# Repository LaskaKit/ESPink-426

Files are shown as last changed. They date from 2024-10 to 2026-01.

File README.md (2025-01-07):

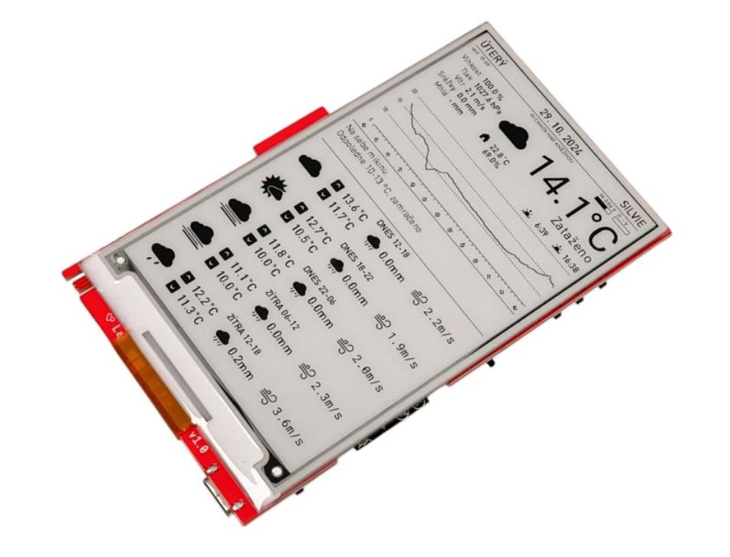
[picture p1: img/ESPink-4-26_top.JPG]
ESPink-4.26 TOP

</br>
# ESPink 4.26" - versatile and low power board with ESP32-S3 for big 4.26" 800x480 ePaper/eInk
Our completely finished and equipped development boards with ESP32 and glued ePaper display became popular not only among DIY makers. We are now expanding our product range with another finished Laskakit ESPink development kit with a 4.26" variant. </br>
It complements the existing family of ready to use ePaper kits such as Laskakit [ESPink-Shelf-2.9 ESP32 e-Paper](https://www.laskakit.cz/laskakit-espink-shelf-2-9-esp32-e-paper/?variantId=14193), [LaskaKit ESPink-4.2 ESP32 e-Paper](https://www.laskakit.cz/laskakit-espink-42-esp32-e-paper-pcb-antenna/?variantId=13538) and LaskaKit [ESPink-Shelf-2.13 ESP32 e-Paper](https://www.laskakit.cz/laskakit-espink-shelf-213-esp32-e-paper/).
If you prefer a standalone board, then we offer the [very low power and versatile ESPink](https://www.laskakit.cz/laskakit-espink-esp32-e-paper-pcb-antenna/?variantId=12419). The board is smaller and more versatile for connecting other ePaper displays.</br>
</br>
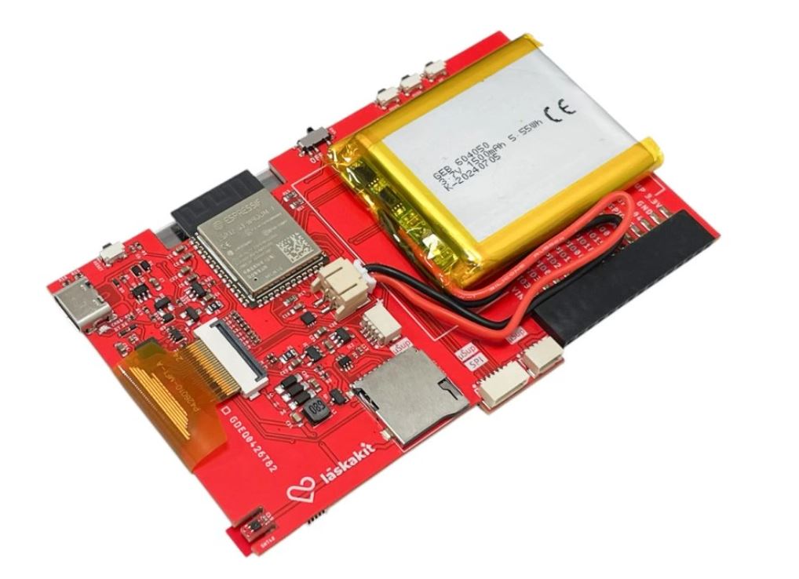
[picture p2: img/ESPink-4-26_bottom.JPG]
ESPink-4.26 TOP
</br>
ESPink-4.26 with ESP32-S3 offers very low power consumption, reasonably sized ePaper with large 800x480px resolution, easy programming thanks to built-in programmer connected to USB-C from which the battery is also charged, connector with unused pins from ESP32-S3 thanks to which additional signals can be brought to the board and last but not least a microSD slot for memory card. </br>
ESPink-4.26 is equipped with two of our universal I2C uŠup connectors to which you can connect various sensors - [SHT40 (temperature, humidity)](https://www.laskakit.cz/laskakit-sht40-senzor-teploty-a-vlhkosti-vzduchu/), [BME280 (tlak, teplota, vlhkost)](https://www.laskakit.cz/arduino-senzor-tlaku--teploty-a-vlhkosti-bme280/), [SCD41 (CO2, temperature, humidity)](https://www.laskakit.cz/laskakit-scd41-senzor-co2--teploty-a-vlhkosti-vzduchu/), [BH1750 (light sensor)](https://www.laskakit.cz/laskakit-bh1750-snimac-intenzity-osvetleni/), [APDS-9960 (gesture sensor)](https://www.laskakit.cz/laskakit-apds-9960-senzor-priblizeni-a-gest/) and lot of other sensors.</br>
Our I2C uŠup connector is compatible with Adafruit Stemma and Qwiik from Sparkfun.</br>
In addition to the I2C uŠup connector, we also have an SPI uŠup connector.</br>
</br>
The board supports the popular Živý Obraz project which greatly simplifies the use of the ePaper display to display photos, (google, outlook, apple) calendar, weather station readings, weather forecasts and much more. No need to write code, just upload the correct type of ePaper and board through the web environment and follow the procedure described in [wiki of project](https://wiki.zivyobraz.eu/).</br>
The firmware you may upload to board through [webpage available on this link](https://zivyobraz.eu/?page=instalace), just choose the board <b>LaskaKit ESPink 3.x</b> aand the type of ePaper <b>GDEQ0426T82</b>. </br>
</br>
If you want to write your own program, go ahead :-)</br>
The [schematic of board you may find on](https://github.com/LaskaKit/ESPink-426/tree/main/HW) and we also wrote several [example codes](https://github.com/LaskaKit/ESPink-426/tree/main/SW), which help a lot with writing of you own firmware for this ESPink-4.26 board.</br>
</br>
Some technical information:</br>
ESPink-4.26 has a switch that completely disconnects the board and ePaper from the power supply. Both battery and USB. </br>
IO pins for I2C bus are used - SDA IO42 and SCL IO2.</br>
The board can be assembled with a SHT40, which is connected to the same I2C bus as the external sensors.</br>
The power supply for the external I2C sensors (uSup), SPI sensors (uSup), mounted SHT40 sensor, Fuel Gauge MAX17048 and ePaper is switched via GPIO pin 47. Active in HIGH.</br>
Battery status is monitored by the Fuel Gauge MAX17048 sensor connected to the same I2C bus.</br>
In addition to the RESET button, there are three other buttons on the board labeled UP (GPIO39), PUSH (GPIO40) and DOWN (GPIO41) - all active in LOW.</br>
IO pins for the SPI bus are used - CS IO46, MOSI IO37, CLK IO14 and MISO IO21.</br>
## The ESPink-4.26 is available on [https://www.laskakit.cz/laskakit-espink-4-26-esp32-s3-e-paper/](https://www.laskakit.cz/laskakit-espink-4-26-esp32-s3-e-paper/)

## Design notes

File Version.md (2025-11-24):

### Version 1.4
- Added one more capacitor 47uF for ESP
#### Version 1.3
- Fuel Gauge replaced by ESP ADC
- Epaper BUSY pin changed from IO36 to IO38
- Epaper CS2 pin changed from IO35 to IO18
- µŠup SPI MOSI pin changed from IO37 to IO3
#### Version 1.2
- LOD changed to RT9080
- Changed pull-ups R18, R19, R20 back from VSENSOR to +3.3V
- Buttons moved far away one from each other
- Rotated uSup connector -90 deg.
#### Version 1.1
- Changed pull-ups R13, R14, R18, R19, R20 and R22 from +3.3V to VSENSOR
- Debounsing for buttons
- Battery connector moved
#### Version 1.0
- Initial | Počáteční

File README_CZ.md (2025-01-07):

ESPink-4.26 TOP
</br>
# ESPink-4.26" - univerzální a velmi úsporná deska s ESP32-S3 pro velký 4.26" 800x480 ePaper

Do obliby nejen bastlířů se dostaly naše už kompletně hotové a osazené vývojové desky s ESP32 a přilepeným ePaper displejem. Rozšiřujeme tak náš sortiment o další hotový vývojový kit Laskakit ESPink o variantu 4.26". </br>
Doplňuje tak stávající rodinu hotových kitů s ePaper jako jsou [Laskakit ESPink-Shelf-2.9 ESP32 e-Paper](https://www.laskakit.cz/laskakit-espink-shelf-2-9-esp32-e-paper/?variantId=14193), [LaskaKit ESPink-4.2 ESP32 e-Paper](https://www.laskakit.cz/laskakit-espink-42-esp32-e-paper-pcb-antenna/?variantId=13538) a [LaskaKit ESPink-Shelf-2.13 ESP32 e-Paper](https://www.laskakit.cz/laskakit-espink-shelf-213-esp32-e-paper/).</br>
Pokud preferuješ samostatnou desku, pak máme v nabídce [velmi úsporný a univerzální ESPink](https://www.laskakit.cz/laskakit-espink-esp32-e-paper-pcb-antenna/?variantId=12419). Deska je menší a univerzálnější pro připojení jiných ePaper displejů. </br>
</br>
ESPink-4.26 TOP</br>
</br>
ESPink-4.26 s ESP32-S3 nabízí velmi nízkou spotřebu, rozumně velký ePaper s velkým 800x480px rozlišením, jednoduché programování díky vestavěnému programátoru připojeného na USB-C ze kterého se zároveň nabíjí akumulátor, konektor s vyvedenými nevyužitými piny z ESP32-S3 díky kterému mohou být do desky přivedeny další signály a v neposlední řadě i microSD slot pro paměťovou kartu. </br>
</br>
ESPink-4.26 má osazeny dva naše univerzální I2C uŠup konektory ke kterým můžeš připojit nejrůznější čidla - [SHT40 (teplota, vlhkost)](https://www.laskakit.cz/laskakit-sht40-senzor-teploty-a-vlhkosti-vzduchu/), [BME280 (tlak, teplota, vlhkost)](https://www.laskakit.cz/arduino-senzor-tlaku--teploty-a-vlhkosti-bme280/), [SCD41 (CO2, teplota, vlhkost)](https://www.laskakit.cz/laskakit-scd41-senzor-co2--teploty-a-vlhkosti-vzduchu/), [BH1750 (osvětlení)](https://www.laskakit.cz/laskakit-bh1750-snimac-intenzity-osvetleni/), [APDS-9960 (senzor gest)](https://www.laskakit.cz/laskakit-apds-9960-senzor-priblizeni-a-gest/) a spoustu další senzorů. Náš I2C uŠup konektor je kompatibilní s Adafruit Stemma a Qwiik od Sparkfun.</br>
Kromě I2C uŠup konektoru máme osazený i SPI uŠup konektor.
</br>
Deska podporuje populární projekt Živý Obraz, který výrazně zjednodušuje použití ePaper displeje k zobrazení fotografií, (google, outlook, apple) kalendáře, kurzů, hodnot z meteostanic, předpovědi počasí a mnoho dalšího. Není nutné psát kód, stačí nahrát správný typ ePaper a desky skrze webové prostředí a dodržet postup popsaný v [dokumentaci](https://wiki.zivyobraz.eu/).</br>
Program nahraješ [přes webové prostředí na této stránce](https://zivyobraz.eu/?page=instalace) a stačí zvolit desku <b>LaskaKit ESPink 3.x</b> a typ ePaperu <b>GDEQ0426T82</b>. </br>
</br>
Pokud si chceš napsat vlastní program, tak do toho :-)</br>
Na našem github máš [schéma desky](https://github.com/LaskaKit/ESPink-426/tree/main/HW) a nezapomněli jsme ani na [vzorové kódy](https://github.com/LaskaKit/ESPink-426/tree/main/SW), které by ti značně měly usnadnit programování a práci s naším ESPink-4.26. </br>
</br>
Pár technických informací:</br>
ESPink-4.26 má přepínač kterým se deska i ePaper kompletně odpojí od napájení. Jak baterie, tak i USB. </br>
IO piny pro I2C sběrnici jsou použity - SDA IO42 a SCL IO2.</br>
Na desce může být osazen SHT40, který je připojen na stejnou I2C sběrnici jako externí čidla.</br>
Napájení pro externí I2C čidla (uŠup), SPI čidla (uŠup), osazené SHT40 čidlo, Fuel Gauge MAX17048 a ePaper je spínán přes GPIO pin 47. Aktivní v HIGH.</br>
Stav baterie je monitorován Fuel Gauge senzorem MAX17048 připojeným na stejnou I2C sběrnici.</br>
Kromě RESET tlačítka jsou na desce osazena další tři tlačítka označená jako UP (GPIO39), PUSH (GPIO40) a DOWN (GPIO41) - všechny aktivní v LOW.</br>
IO piny pro SPI sběrnici jsou použity - CS IO46, MOSI IO37, CLK IO14 a MISO IO21.</br> 

## ESPink-4.26 je k zakoupení na našem e-shopu [https://www.laskakit.cz/laskakit-espink-4-26-esp32-s3-e-paper/](https://www.laskakit.cz/laskakit-espink-4-26-esp32-s3-e-paper/)

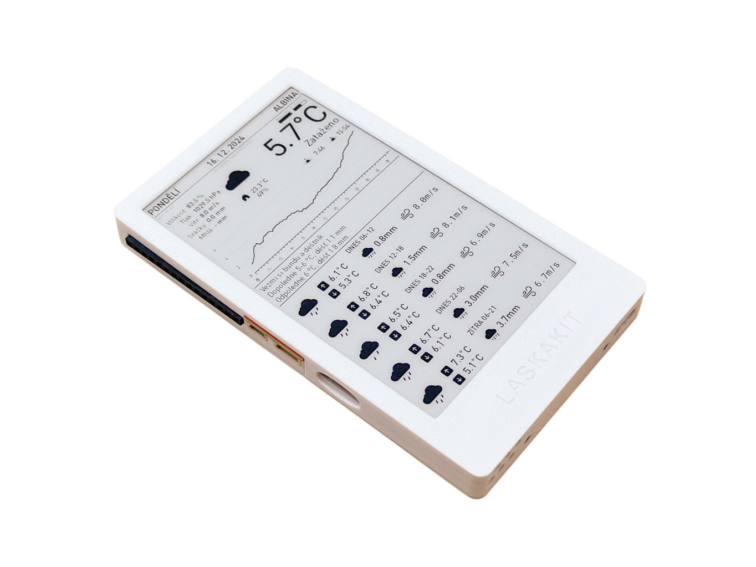
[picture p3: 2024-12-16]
img/laskakit--krabicka-pro-espink-4-26-2.jpg

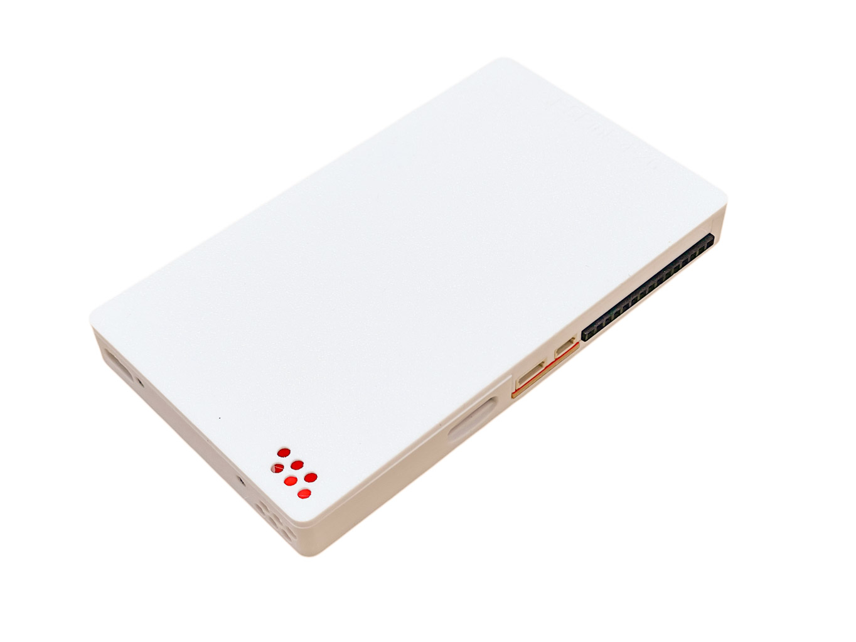
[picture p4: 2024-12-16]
img/laskakit--krabicka-pro-espink-4-26-3.jpg

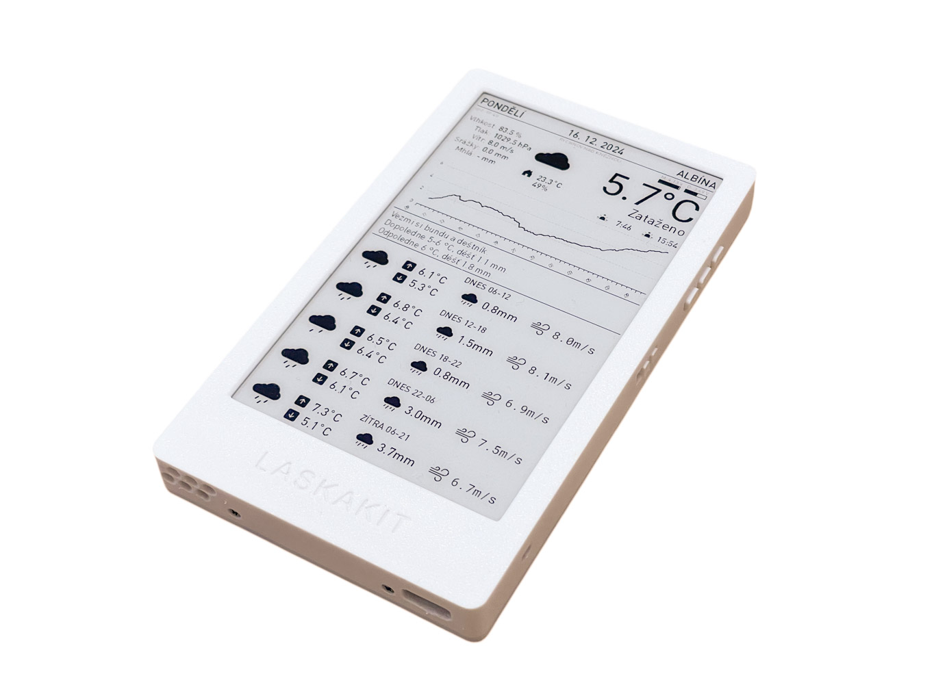
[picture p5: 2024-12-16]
img/laskakit--krabicka-pro-espink-4-26-1.jpg

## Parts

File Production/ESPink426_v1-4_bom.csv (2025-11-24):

Comment | Designator | Footprint | LCSC Part #
1.3M | R25 | R0402
1M | R8 R24 | R0402
1TS003B-1600-3500A | DOWN PUSH RESET UP | 1TS003B16003500A
1k | R5 | R0402
1uF | C7 | C0603
1uF | C29 C30 C31 | C0402
1uF/25V | C9 C10 C11 C16 | C0402
1x15 | JP1 | 1X15-F-SMD
2.2R | R9 | R0402
3.3k | R10 | R0402
4.7k | R13 R14 | R0603
4.7uF/25V | C3 C8 C12 C13 C14 C15 | C0402
4.7uF/25V | C20 | C0603
5.1k | R15 R16 | R0402
5.8A/30V/35mΩ | Q4 | SOT23-3 | C20917
10k | R1 R2 R3 R6 R11 R18 R19 R20 R22 | R0402
10uF/16V | C4 C5 C24 C25 | C0603
10uF/25V | C21 | C0603
22uF | C26 | C0603
47k | R4 R7 | R0402
47uF | C2 C22 | C0603 | C178330
47uH/1A | L1 | SMNR4020
100k | R12 R23 | R0402
100n | C27 C28 | C0402
100nF | C1 | C0603
100nF | C6 C17 C18 C19 | C0402
AO3401 | Q5 Q7 | SOT23
BAT60B | D3 | SOD323-R
CH9102F | IC3 | QFN24-4X4
DMG2305UX | Q2 | MICRO3 | C144153
ESP32-S3-WROOM-1-N16R8 | IC1 | ESP32S3WROOM1N16
GDEQ0426T82 | U$4 | GDEQ0426T82
JST-PH-2_SMD/90SMD | BATTERY | S2B-PH-SM4 | C47647
JST-SH-4_RA | J2 | 1X04_1MM_RA
JST-SH-4_VERT | J3 | 1X04_1MM_RA
LESD5D5.0CT1G | D7 D8 D9 | LESD5D50CT1G
MBR0530 | D4 D5 D6 | SOD123-F
MICRO_SD | SD_CARD | MICRO_SD | C91145
MMDT3904 | Q1 | SC70-6 | C268586
MMDT5401 | Q3 | SC70-6 | C54540
RED | CHRG | CHIP-LED0603 | C2286
RT9080-33GJ5 | IC2 LDO | SOT94P280X100-5N
SHT40 | SHT40 | SHT40
SMF05C | IC4 | SOT65P210X110-6N | C558425
SSSS811101 | SW1 | SSSS811101
TP4054 | U1 | SOT-23-5 | C32574
USB-C_GT-USB-7010B | J4 | G-SWITCH_GT-USB-7010B | C2837092
USUP_SPI_CONNECTOR | J5 | 1X06_1MM_RA

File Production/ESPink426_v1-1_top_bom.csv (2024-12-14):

Comment | Designator | Footprint | LCSC Part #
1M | R8 | R0402
1TS003B-1600-3500A | DOWN PUSH RESET UP | 1TS003B16003500A
1k | R5 | R0402
1uF | C7 | C0603
1uF | C29 C30 C31 | C0402
1uF/25V | C9 C10 C11 C16 | C0402
2.2R | R9 | R0402
4.7k | R13 R14 | R0603
4.7uF | C5 | C0603 | C99229
4.7uF/25V | C3 C8 C12 C13 C14 C15 | C0402
4.7uF/25V | C20 | C0603
5.1k | R15 R16 | R0402
10k | R1 R2 R3 R11 R18 R19 R20 R22 | R0402
10uF/25V | C21 | C0603
22uF | C4 C22 C23 C24 C25 C26 | C0603
47uF | C2 | C0603 | C178330
47uH/1A | L1 | SMNR4020 | C467067
100k | R12 R23 | R0402
100n | C27 C28 | C0402
100nF | C1 | C0603
100nF | C6 C17 | C0402
100nF | C18 | C0603
100nF | C19 | C0402
330 | R10 | R0402
AO3400A | Q4 | SOT23-3 | C20917
AO3401 | Q5 Q7 | SOT23
AP2191WG-7 | IC7 | SOT25 | C141321
BAT60B | D1 D2 D3 | SOD323-R
CH9102F | IC3 | QFN24-4X4
ESP32-S3-WROOM-1-N16 | IC1 | ESP32S3WROOM1N16
GDEQ0426T82 | U$4 | GDEQ0426T82
HT7833 | LDO | SOT23-5 | C164106
JST-PH-2/90SMD | BATTERY | S2B-PH-SM4 | C47647
JST-SH-4_RA | J2 | 1X04_1MM_RA | C145956
JST-SH-4_VERT | J3 | 1X04_1MM_RA | C145956
LESD5D5.0CT1G | D7 D8 D9 | LESD5D50CT1G
MAX17048 | U2 | TDFN-8 | C2682616
MBR0530 | D4 D5 D6 | SOD123-F
ME6211C33M5G | IC2 | SOT23-5
MICRO_SD | SD_CARD | MICRO_SD | C91145
MMDT3904 | Q1 | SC70-6 | C268586
POLIFUSE0500805L | F1 F2 | 0805L
RED | CHRG | CHIP-LED0603 | C2286
SHT40 | SHT40 | SHT40
SMF05C | IC4 | SOT65P210X110-6N | C558425
SSSS811101 | SW1 | SSSS811101
TP4054 | U1 | SOT-23-5 | C32574
USB-C_2-16PIN | J4 | USBC_USB-C-16P-5 | C2837092
USUP_SPI_CONNECTOR | J5 | 1X06_1MM_RA
1x15P | JP1 | 1x15P | C5142248

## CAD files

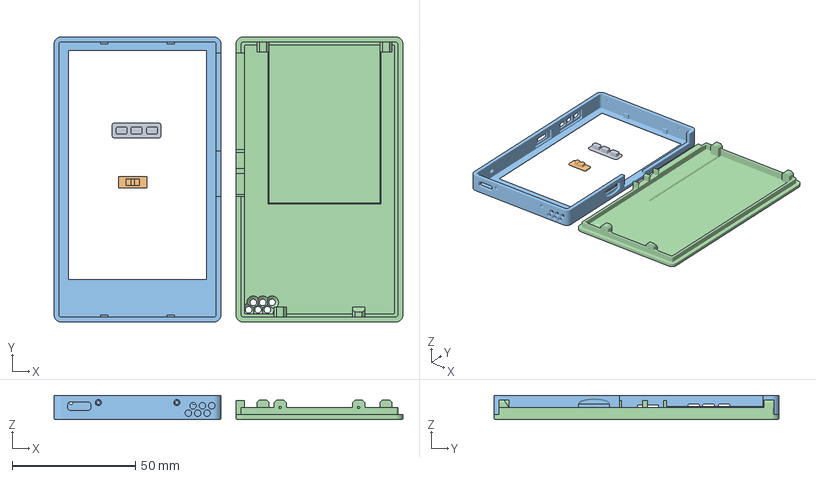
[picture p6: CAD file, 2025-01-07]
3D/ESPink-426_case_v1-1.3mf
141.8 x 115.9 x 9.80 mm
buttons v22
switch v8
Top_cover v73
Bottom_cover v28

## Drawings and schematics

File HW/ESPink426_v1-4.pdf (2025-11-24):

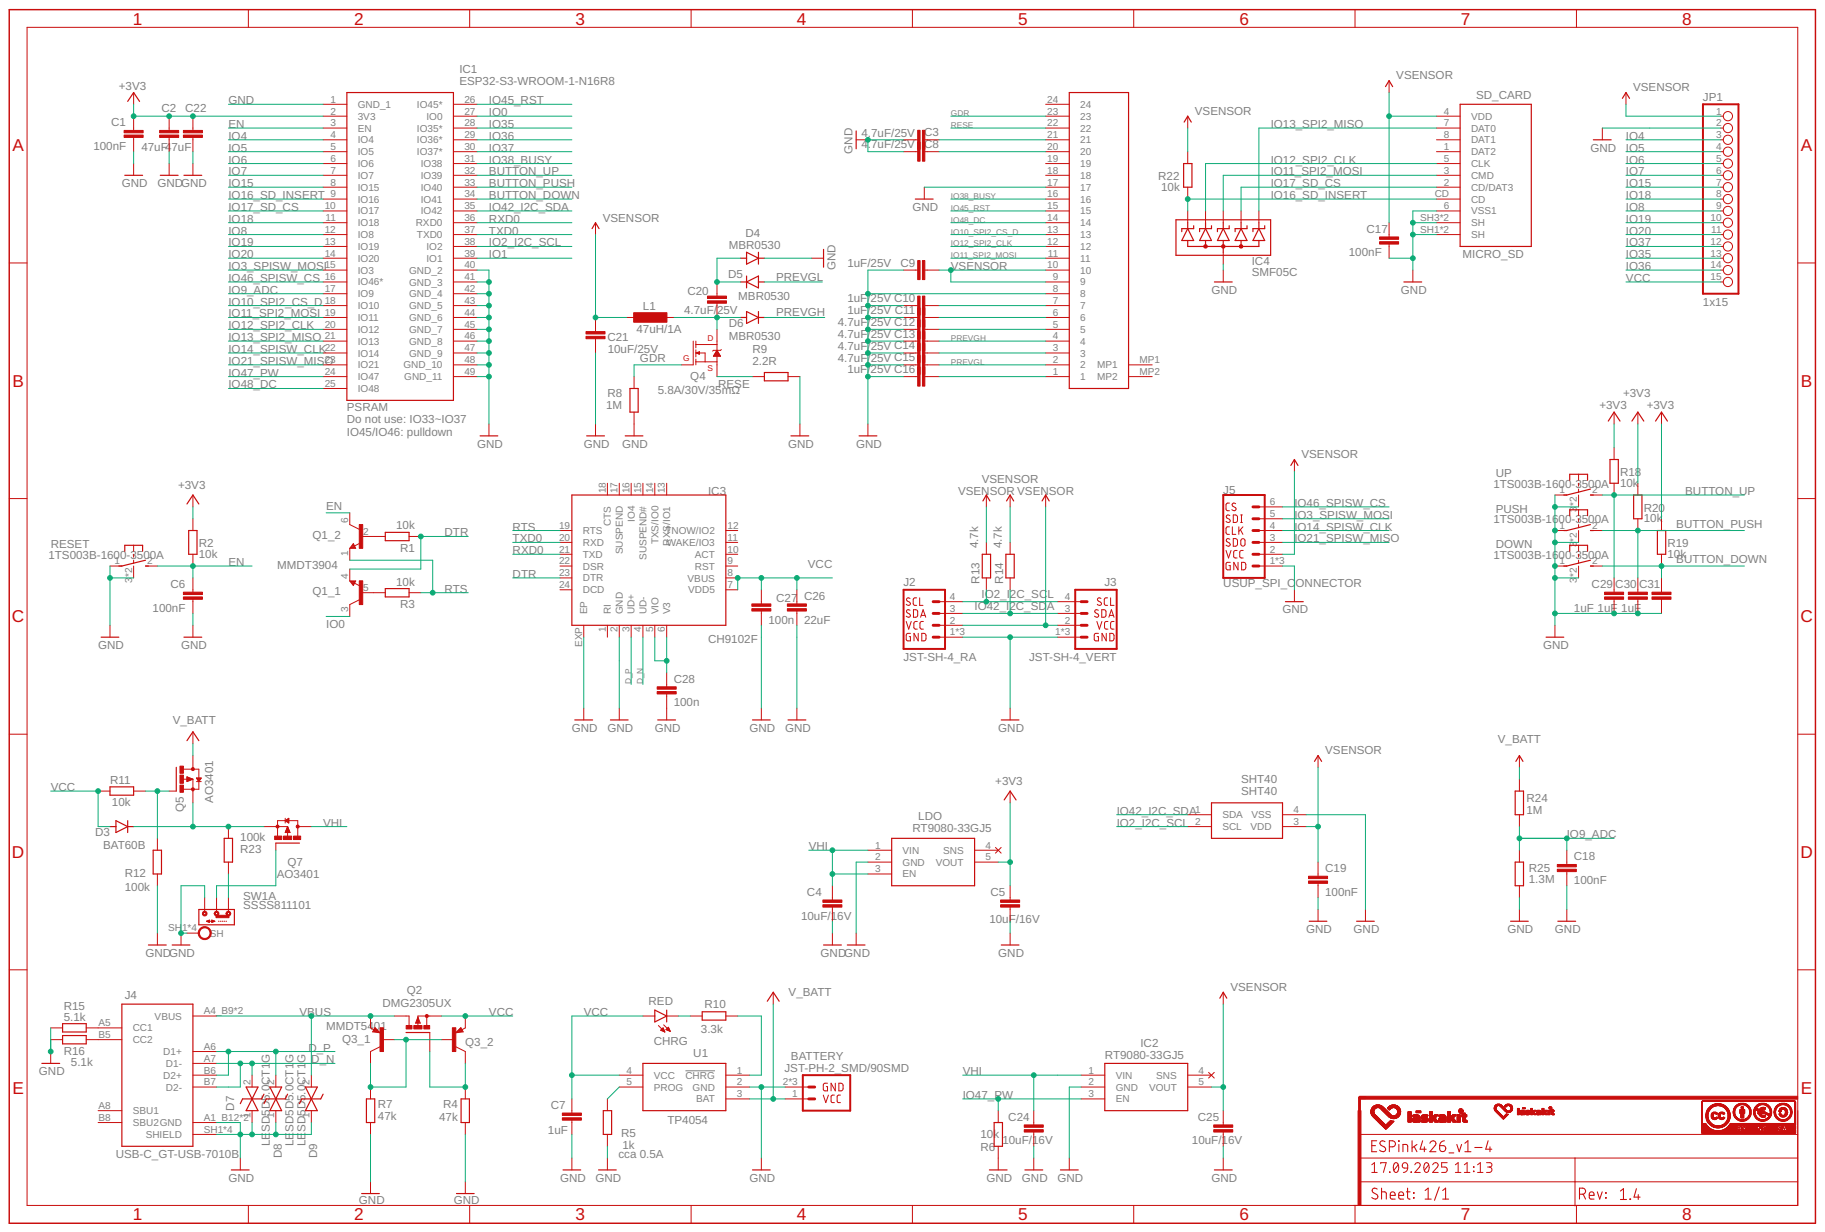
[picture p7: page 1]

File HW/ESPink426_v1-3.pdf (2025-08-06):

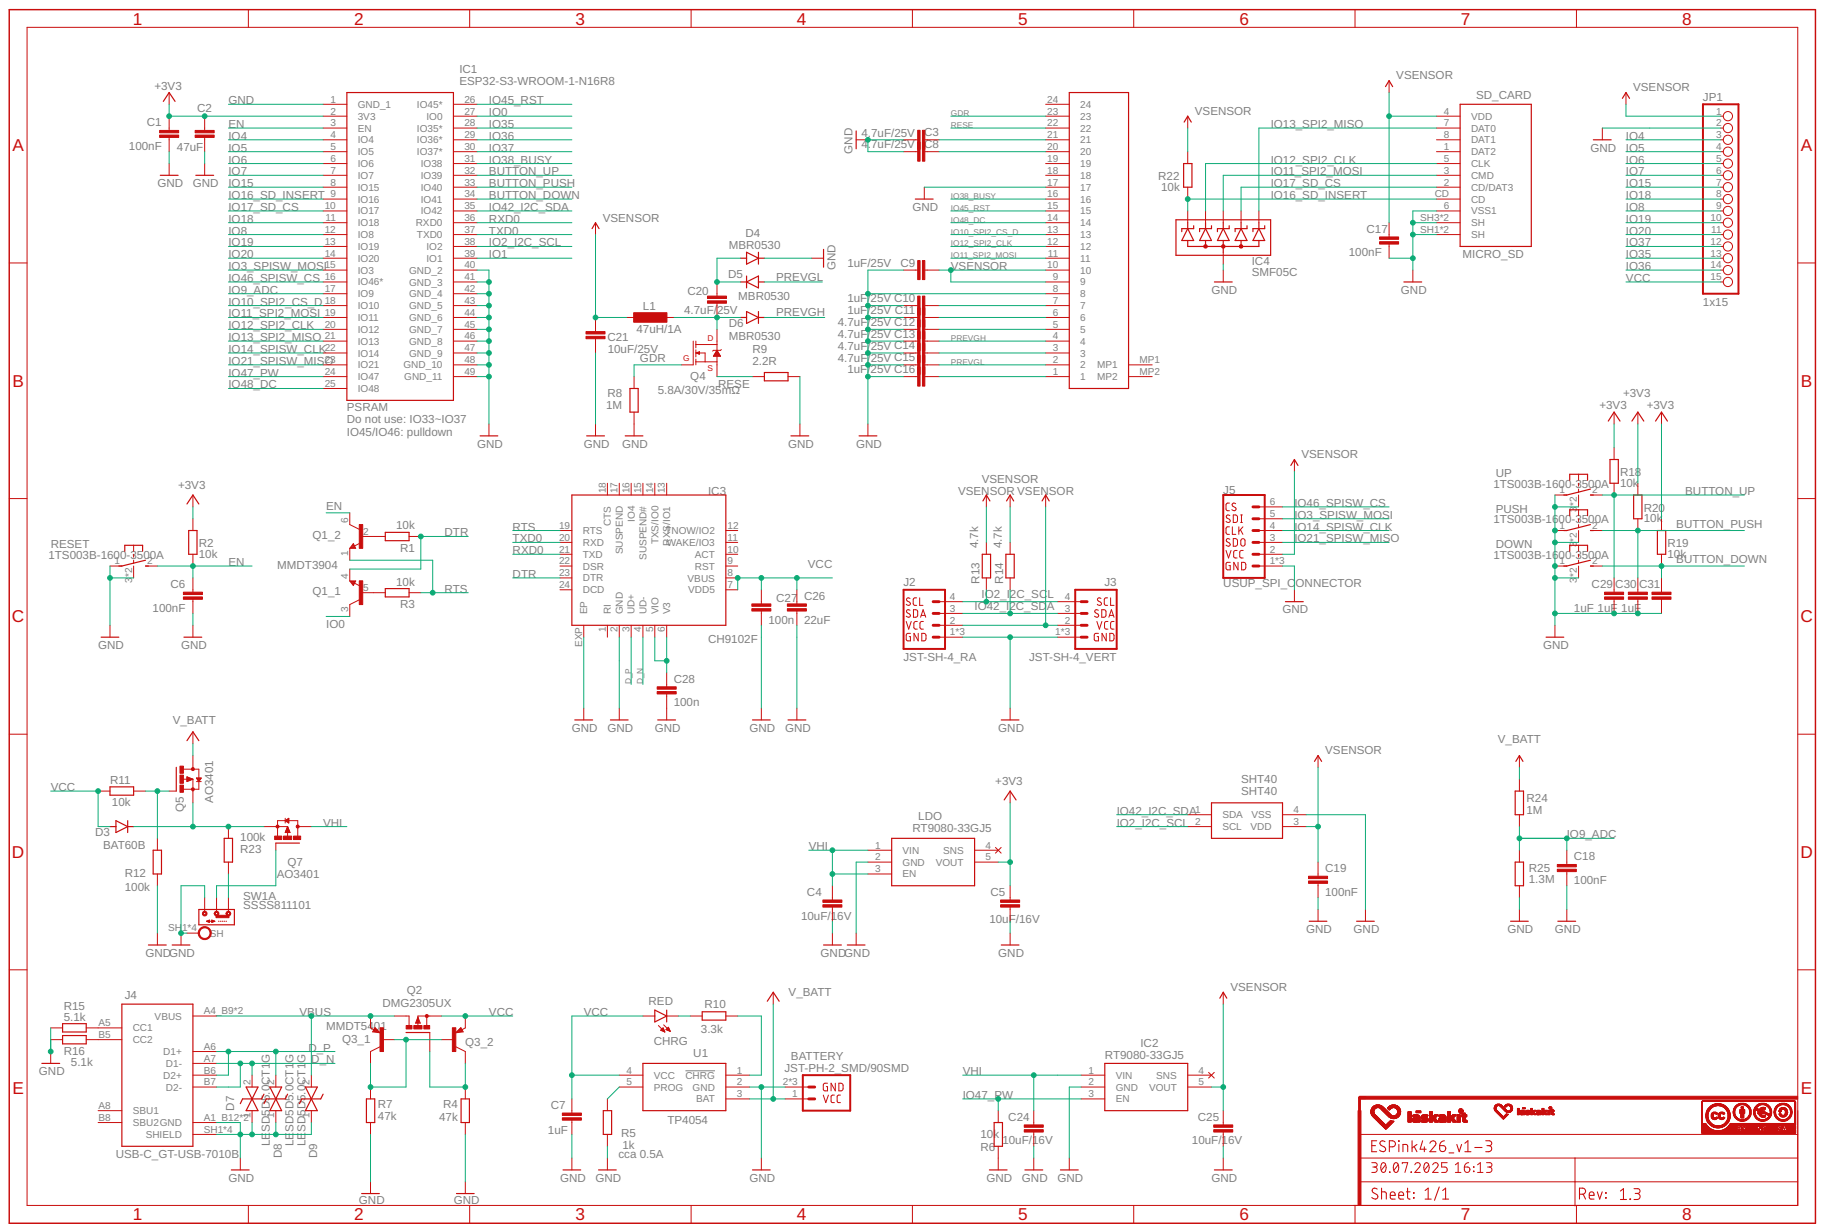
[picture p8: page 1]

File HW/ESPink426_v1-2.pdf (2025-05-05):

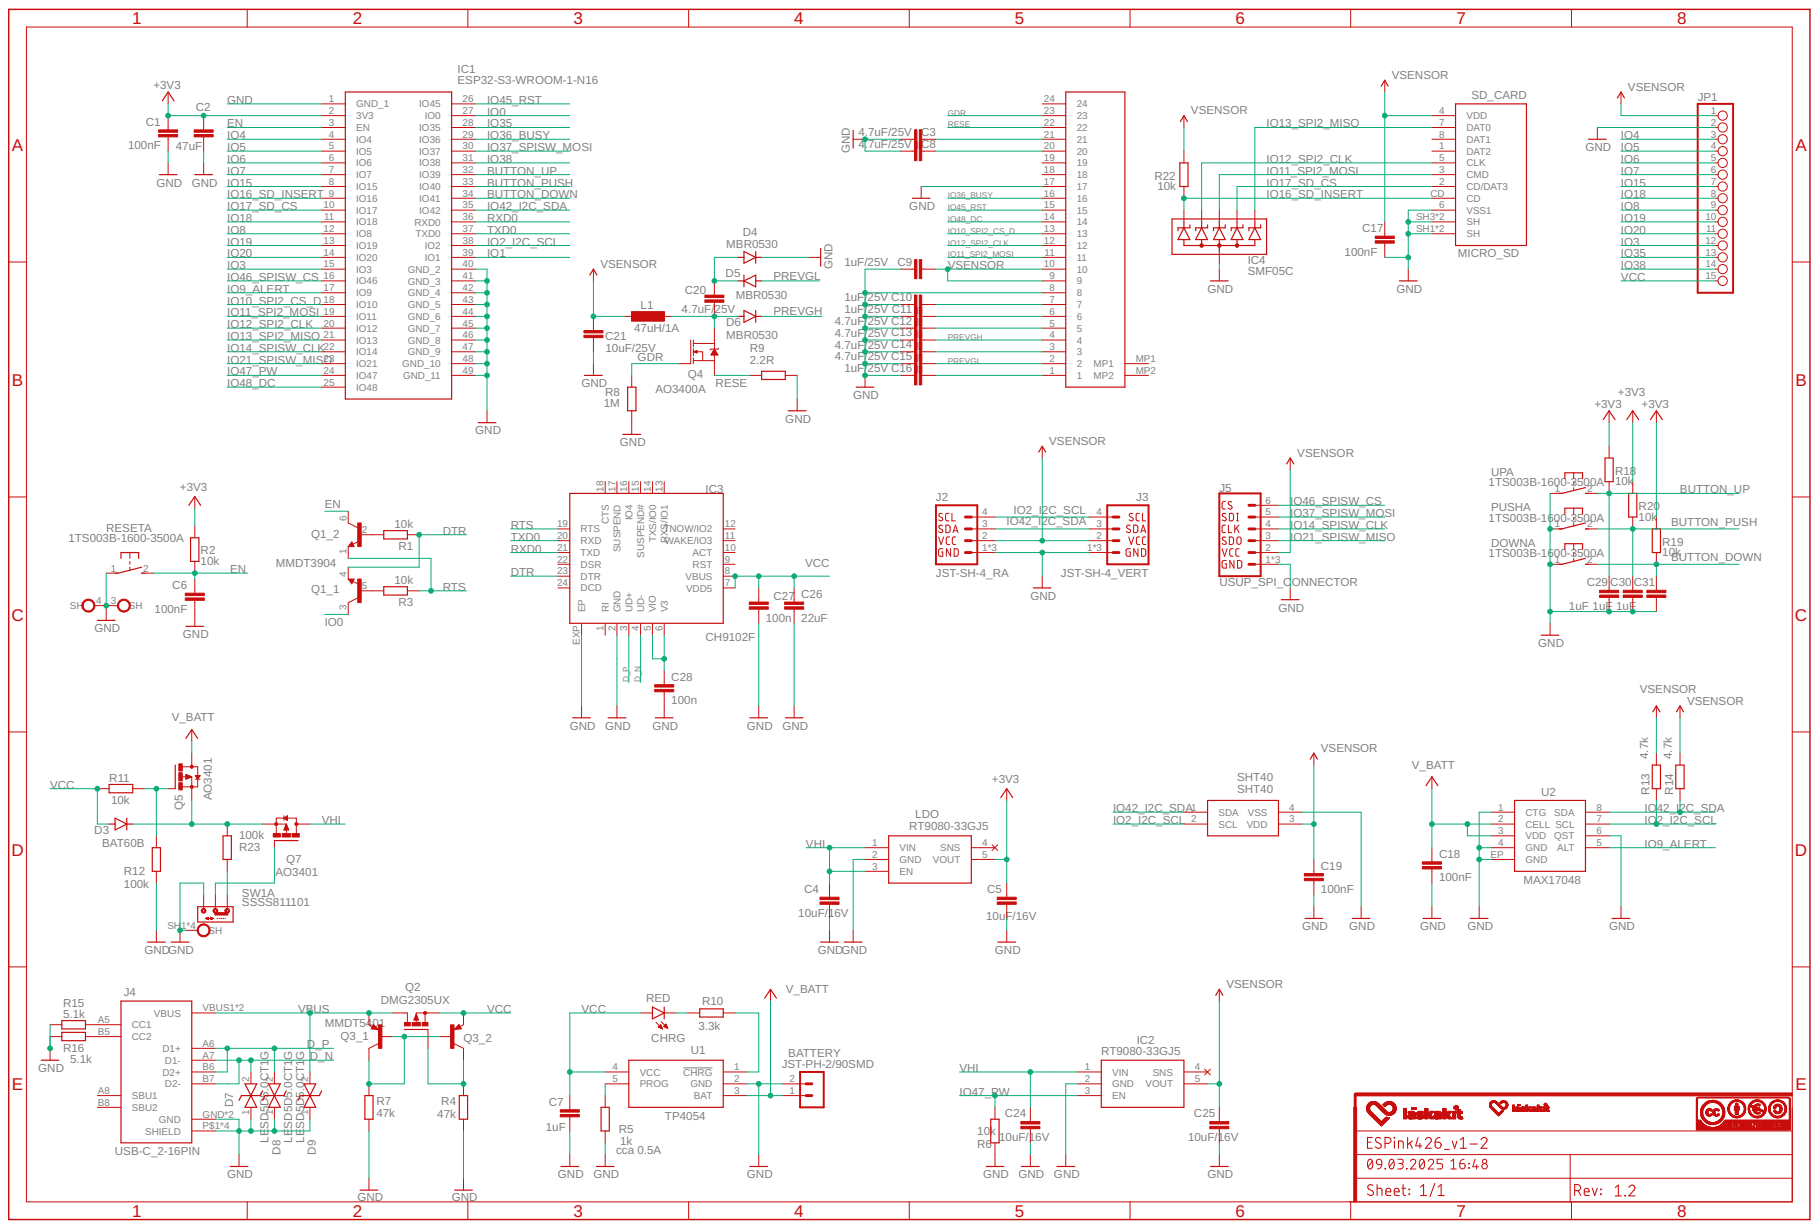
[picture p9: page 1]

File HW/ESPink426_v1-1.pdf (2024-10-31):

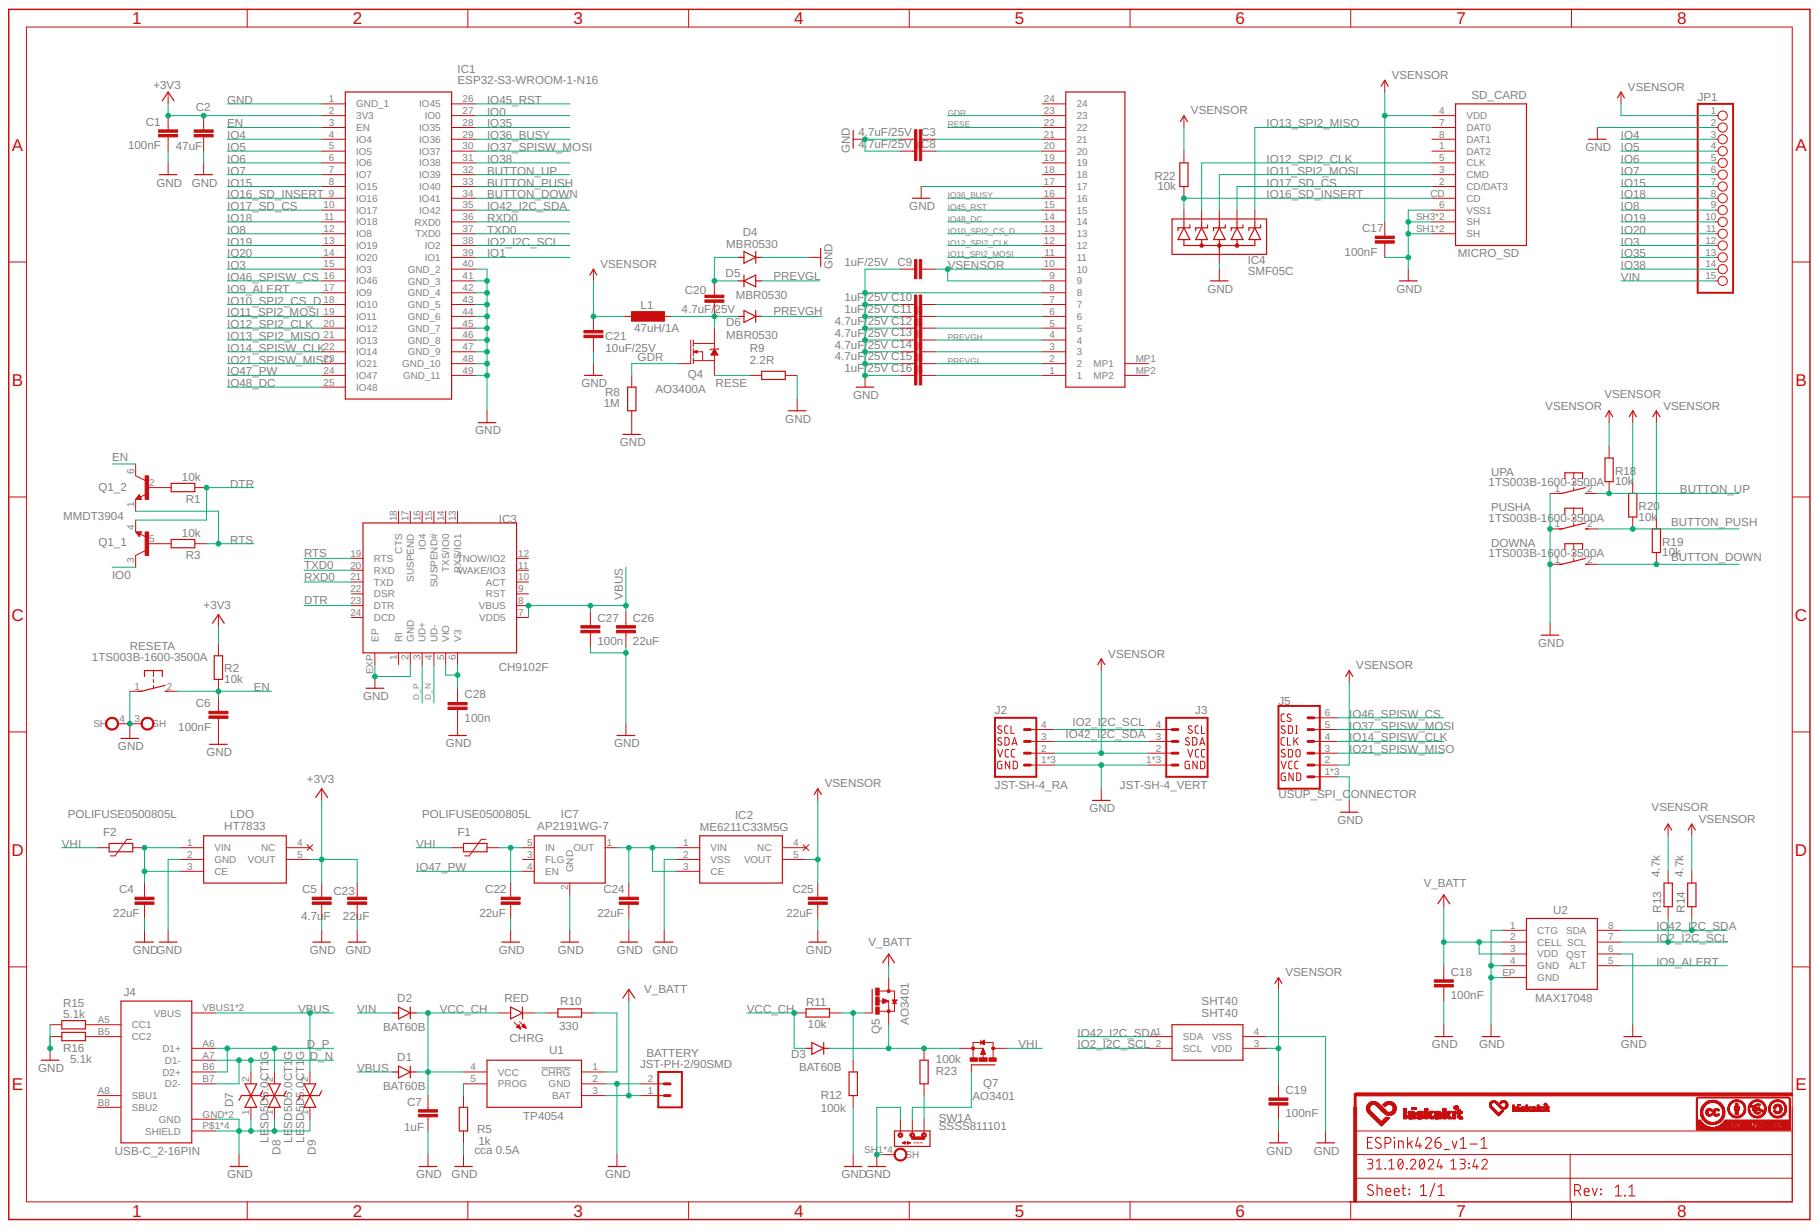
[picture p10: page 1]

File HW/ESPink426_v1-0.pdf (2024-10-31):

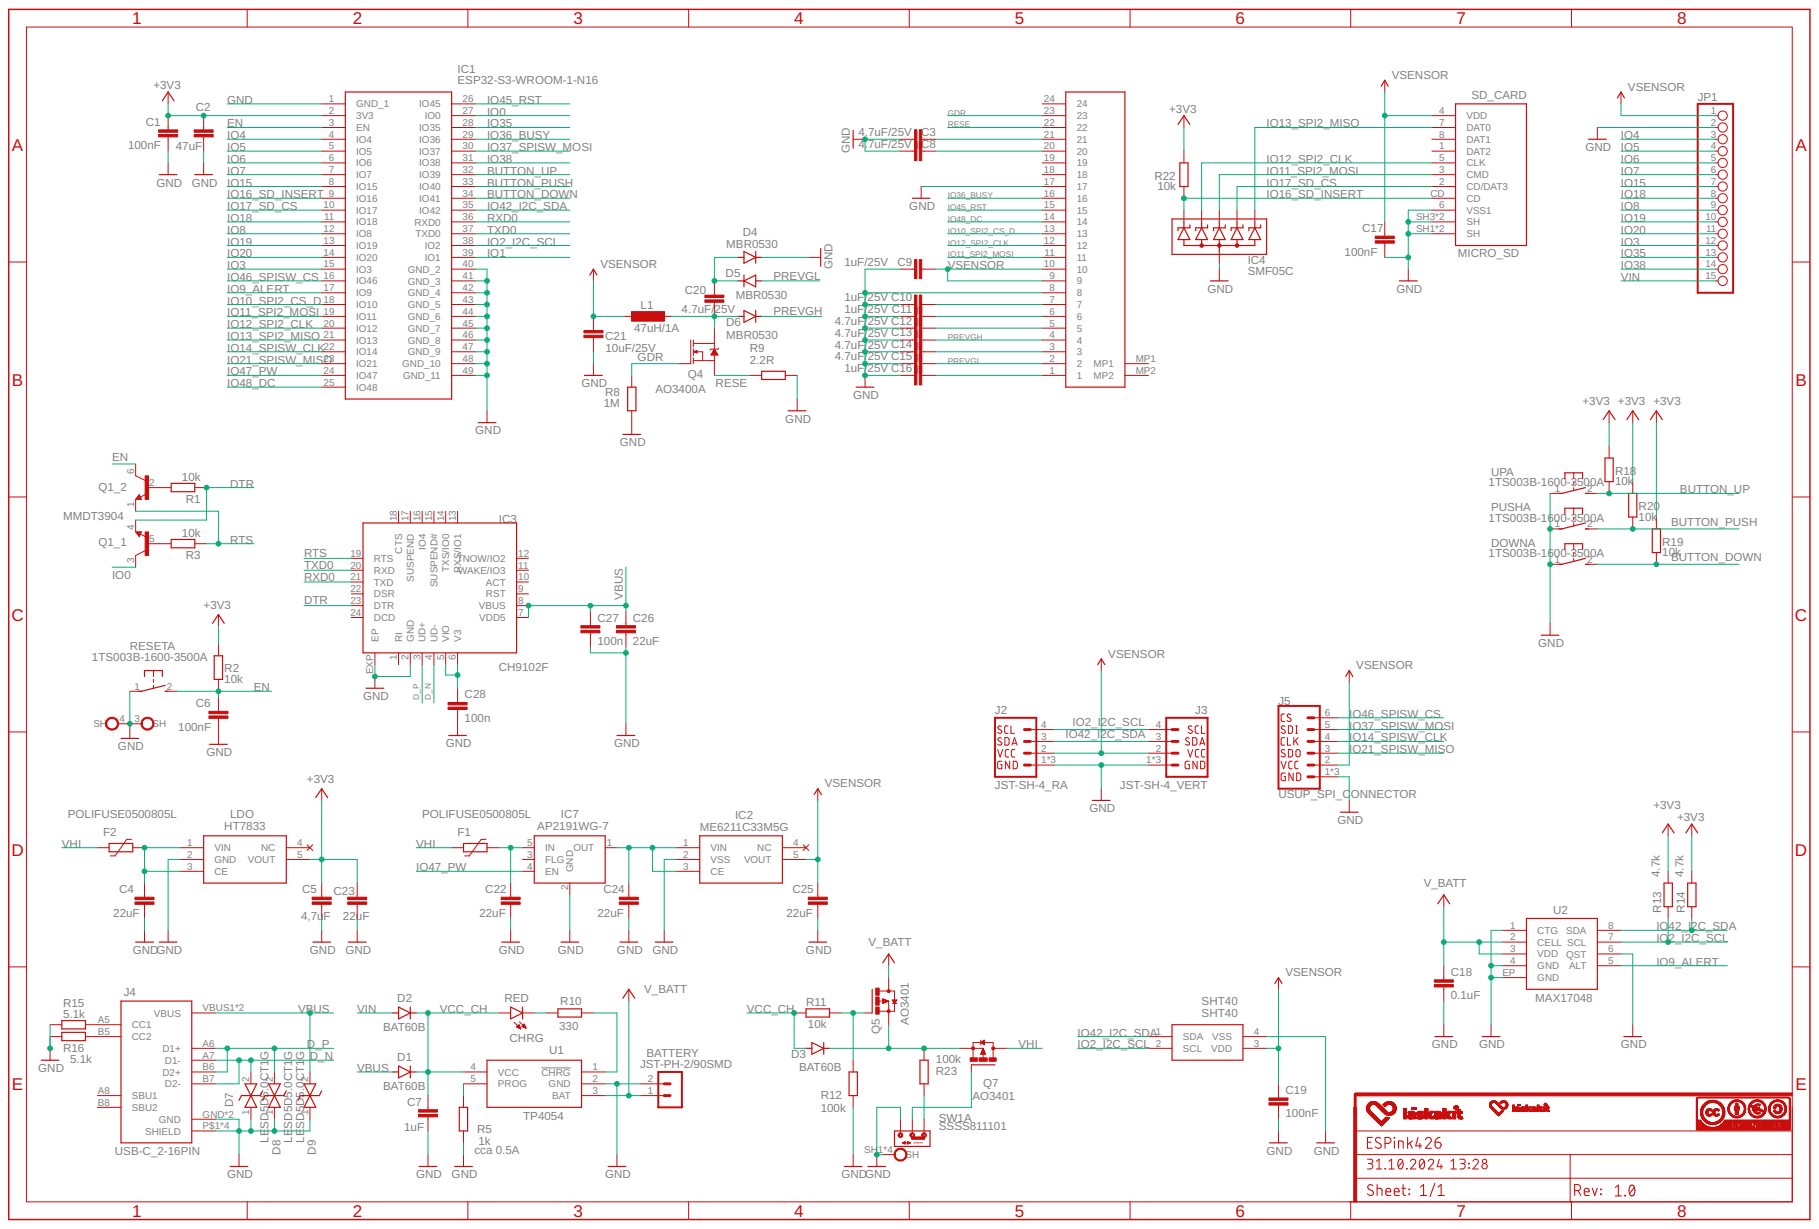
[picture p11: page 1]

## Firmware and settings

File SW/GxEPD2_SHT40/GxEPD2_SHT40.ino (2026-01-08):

/* Display test for LaskaKit ESPink-4.26
 * 
 * Board:   LaskaKit ESPink-4.26   https://www.laskakit.cz/laskakit-espink-esp32-e-paper-pcb-antenna/
 *
 * Libraries:
 * SHT40: https://github.com/Sensirion/arduino-i2c-sht4x
 * EPD library: https://github.com/ZinggJM/GxEPD2_4G
 * 
 * Email:podpora@laskakit.cz
 * Web:laskakit.cz
 */
 
#define ENABLE_GxEPD2_GFX 1

#include <GxEPD2_4G_4G.h>
#include <GxEPD2_4G_BW.h>
#include <SensirionI2cSht4x.h>
#include <Wire.h>

// macro definitions
#ifdef NO_ERROR
#undef NO_ERROR
#endif
#define NO_ERROR 0

// Fonts
#include "OpenSansSB_12px.h"
#include "OpenSansSB_50px.h"
 
//MOSI/SDI    11
//CLK/SCK     12
//SS/CS       10
#define DC    48 
#define RST   45  
#define BUSY  38
#define POWER 47
#define SDA   42
#define SCL   2
#define BAT   9

GxEPD2_4G_4G < GxEPD2_426_GDEQ0426T82, GxEPD2_426_GDEQ0426T82::HEIGHT / 2 > display(GxEPD2_426_GDEQ0426T82(SS, DC, RST, BUSY)); // GDEQ0426T82 480x800, SSD1677 (P426010-MF1-A)

// SHT40
SensirionI2cSht4x sensor;
static char errorMessage[64];
static int16_t error;

uint8_t sht4x_addr_found = 0x00;

// ADC
float vBat = 0.0;

static bool initSHT4xAutoAddr(float& aTemperature, float& aHumidity) {
  const uint8_t addrs[] = { 0x44, 0x45, 0x46 };

  for (uint8_t i = 0; i < sizeof(addrs); i++) {
    uint8_t addr = addrs[i];

    Serial.printf("Trying SHT4x at I2C address 0x%02X ...\n", addr);

    sensor.begin(Wire, addr);

    sensor.softReset();
    delay(10);

    uint32_t serialNumber = 0;
    error = sensor.serialNumber(serialNumber);
    if (error != NO_ERROR) {
      Serial.print("  serialNumber() failed: ");
      errorToString(error, errorMessage, sizeof errorMessage);
      Serial.println(errorMessage);
      continue;
    }

    delay(20);
    error = sensor.measureLowestPrecision(aTemperature, aHumidity);
    if (error != NO_ERROR) {
      Serial.print("  measureLowestPrecision() failed: ");
      errorToString(error, errorMessage, sizeof errorMessage);
      Serial.println(errorMessage);
      continue;
    }

    // success
    sht4x_addr_found = addr;
    Serial.printf("SHT4x found at 0x%02X, serialNumber: %lu\n", addr, (unsigned long)serialNumber);
    Serial.print("aTemperature: "); Serial.print(aTemperature);
    Serial.print("\t aHumidity: ");  Serial.println(aHumidity);
    return true;
  }

  Serial.println("SHT4x not found on 0x44/0x45/0x46.");
  return false;
}

void setup() {
  Serial.begin(115200);

  // turn on power to display
  pinMode(POWER, OUTPUT);
  digitalWrite(POWER, HIGH);   // turn the Display on (HIGH is the voltage level)
  Serial.println("Display power ON");
  delay(500);   

  Wire.begin(SDA, SCL);

  // read the voltage
  vBat = analogReadMilliVolts(BAT) * 1.769 / 1000; // the ratio of divider, R2=1.3M; R1=1M
  Serial.println((String)"VCELL V   : "+ vBat + "V");

  /*----------- SHT40 / SHT4x -----------*/
  float aTemperature = NAN;
  float aHumidity = NAN;

  bool sht_ok = initSHT4xAutoAddr(aTemperature, aHumidity);
  if (!sht_ok) {
    // fallback values to show something on display
    aTemperature = NAN;
    aHumidity = NAN;
  }

  display.init(115200);

  display.setRotation(3);
  display.fillScreen(GxEPD_WHITE);  // white background
  display.setTextColor(GxEPD_BLACK);  // black font

  display.setFullWindow();
  display.firstPage();
  do {
    display.setCursor(5, 50);
    display.setFont(&OpenSansSB_50px);

    if (sht_ok) {
      display.print(String(aTemperature, 1)); 
      display.print("  ");
      display.print(String(aHumidity, 0)); 
    } else {
      display.print("--.-  --");
    }

    display.setFont(&OpenSansSB_12px);
    display.setCursor(30, 70);
    display.println(" degC");
    display.setCursor(150, 70);
    display.println(" % Rh");

    display.setFont(&OpenSansSB_12px);
    display.setCursor(5, 90);
    if (sht_ok) {
      display.print("SHT4x I2C: 0x");
      display.print(String(sht4x_addr_found, HEX));
    } else {
      display.print("SHT4x I2C: not found");
    }

    display.setFont(&OpenSansSB_50px);
    display.setCursor(5, 150);
    display.print(String(vBat, 1)); 

    display.setFont(&OpenSansSB_12px);
    display.setCursor(5, 170);
    display.print("Battery voltage, V");
  }
  while (display.nextPage());

  delay(100);
  digitalWrite(POWER, LOW); // disable power supply for ePaper

  // deep sleep mode
  esp_sleep_enable_timer_wakeup(300 * 1000000);
  delay(200);
  esp_deep_sleep_start();
}

void loop() {
}

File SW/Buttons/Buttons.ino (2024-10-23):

/* Buttons test for LaskaKit ESPink-4.26
 * 
 * Board:   LaskaKit ESPink-4.26   https://www.laskakit.cz/laskakit-espink-esp32-e-paper-pcb-antenna/
 *
 * 
 * Email:podpora@laskakit.cz
 * Web:laskakit.cz
 */
 
 // constants won't change. They're used here to set pin numbers:
const int buttonUP    = 39;
const int buttonPUSH  = 40;
const int buttonDOWN  = 41;

// variables will change:
int buttonStateUP   = 0;
int buttonStatePUSH = 0;
int buttonStateDOWN = 0;

void setup() {
  Serial.begin(115200);

  // initialize the pushbutton pin as an input:
  pinMode(buttonUP, INPUT);
  pinMode(buttonPUSH, INPUT);
  pinMode(buttonDOWN, INPUT);
}

void loop() {
  // read the state of the pushbutton value:
  buttonStateUP = digitalRead(buttonUP);
  buttonStatePUSH = digitalRead(buttonPUSH);
  buttonStateDOWN = digitalRead(buttonDOWN);

  // check if the pushbutton is pressed. If it is, the buttonState is HIGH:
  if (buttonStateUP == LOW) {
    Serial.println("Button UP pressed");
  } 
  if (buttonStatePUSH == LOW) {
    Serial.println("Button PUSH pressed");
  } 
  if (buttonStateDOWN == LOW) {
    Serial.println("Button DOWN pressed");
  } 
}

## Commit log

2024-12-14 new ver
    [ESPink426_v1-1_top_bom.csv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]
2025-05-05 renamed to old
    [ESPink-426_case_v1-1_old.3mf]
2025-05-05 need to fix, new ver has SHT40 on 0x46
    [GxEPD2_SHT40.ino]
2025-07-28 new data
    [ESPink426_v1-3_bom.csv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]
2025-07-31 folder change
    [ESPink426_v1-2_top_bom.csv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]
2025-07-31 update for new board ver
2025-09-12 usb connect tor is closer to wall
    [ESPink-426_case_from_v1-2.3mf]
2025-12-30 BUSY pin changed to 38
2026-02-18 stand added
    [ESPink-426_case_from_v1-2.3mf]
2026-05-22 moved to https://github.com/LaskaKit/Live
    [ESPink-426_case_from_v1-2.3mf, ESPink-426_case_v1-1_old.3mf]
